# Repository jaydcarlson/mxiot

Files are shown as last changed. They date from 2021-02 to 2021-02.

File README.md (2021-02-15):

# mxiot
mxiot is a low-cost hardware prototyping platform to help you explore switching small IoT projects from bare-metal to a secure-boot-capable WiFi/BT-connected Embedded Linux system capable of running rudimentary C/C++, as well as applications written in almost any modern language or application framework (like Qt, Rust, Ruby, Python, Node.js, or .NET Core).

The heart of mxiot is the i.MX6ULZ, a 900 MHz Cortex-A7 microprocessor available [direct from NXP for $2.68](https://www.nxp.com/part/MCIMX6Z0DVM09AB#/) (even in single quantities). These are drop-in compatible with the i.MX6UL and i.MX6ULL.

mxiot pinout

### Features
The i.MX6ULZ is stripped down to the basics, but there's plenty there for most always-on IoT projects. The board exposes:
 - 3 UARTs (one with hardware flow-control signals, and one dedicated to the console)
 - Two I2C peripherals (one shared with one of the UARTs)
 - SPI with 2 chip-select signals
 - I2S with separate BCLK/WS signals for TX and RX paths.
 - 4x PWM outputs
 - Two USB ports

In addition to the DRAM and SD Card socket necessary for booting, mxiot also sports a small complement of on-board peripherals:
 - WiFi and Bluetooth connectivity
 - 4x 12-bit analog inputs, care of the Texas Instruments TLA2024
 - APA102 addressable RGB LED
 - QSPI Flash (that you can optionally boot from)
 - Pushbutton

WiFi and BLE are handled by whatever 44-pin standard SDIO-interfaced WiFi/BT *module du jour* you'd like to populate; the board supports all physically-compatible Ampak modules, as well as extremely low-cost alternatives, like the RTL8723BS modules regularly found for [around $2 from AliExpress](https://www.aliexpress.com/wholesale?catId=0&initiative_id=SB_20210214115323&SearchText=rtl8723bs), Taobao, or other distributors in Asia.

The design is open-source, and more importantly, the BOM has wide availability and doesn't lean on ICs with limited documentation or support. This means you can prototype your project around the mxiot and then copy the guts into your own design to optimize for size, power consumption, cost, or expanded functionality.

### What if I don't have Altium?
You can [download a ZIP of the repo](https://github.com/jaydcarlson/mxiot/archive/master.zip) and upload this file directly to [Altium's online viewer](https://www.altium.com/viewer/) to interact with the PCB, schematic, BOM, and 3D model of the design without having to download any software. The repo also contains a schematic and gerbers for offline viewing.

### Supports 4-layer and 6-layer stack-ups
For the sake of compactness, mxiot tightly arranges parts onto a dense 6-layer PCB measuring only 2.3 x 0.8 inches (58 x 20mm). Having said that, I've done many lower-cost 4-layer designs with mostly single-sided placements around the same guts of this board without any routing issues.

### Security
I'm a hardware guy, not a cybersecurity consultant, so I know that it's really easy to roll your eyes when people start talking about secure-boot and key storage. But seriously, folks, if you are making devices that you're going to sell to people that will connect to the internet, you have an ethical obligation to think through the security implications. You should be prototyping around hardware that has the underlying capabilities that allow you to turn on security measures during the design cycle.

The i.MX6's OTP key storage, TrustZone, and secure-boot capabilities let you establish a chain of trust from the boot ROM, to U-Boot, to the kernel, and an encrypted rootfs, which will allow you to store private data (like keys!) without having to worry as much about physical device security. You can also transport firmware updates over unencrypted channels and not have to worry about your image being reverse-engineered or modified.

### What about...?
 - *...the Raspberry Pi Zero?* While it has plenty of DRAM, the older ARM11 processor is incompatible with newer application frameworks. There's also no pathway to using the processor in a custom design, and no secure boot capability.
 - *...the Allwinner V3s or F1C100s SIPs?* These are fine for C/C++ applications or very simple Python scripts, but the V3s lacks sufficient RAM to run large, modern application frameworks, and the F1C200s is an older ARM9 cores that have dwindling software support and no security features.
 - *...the Microchip SAMA5D27 or SAM9X60 SIPs?* These both cost twice as much as the combined cost of the i.MX6ULZ and 512MB DDR3, while offering inferior performance as well as the software compatibility issues mentioned above.
 - *...the OSD32MP15x or OSD335x modules?* Unless you're literally assembling no more than a handful of units for the entirety of the project's lifecycle, these are way too expensive to justify the time savings when compared to an iMX6UL/ULL/ULZ design.

### What if I need an LCD, CSI, Ethernet, CAN, or industrial temp grades?
Grab the mxiot schematics as a starting point, but solder down a full-featured i.MX6ULL. These come in tons of different SKUs that mix and match peripherals, operating frequencies, and temperature grades. All of these are 100% electrically and mechanically compatible (in fact, mxiot started out as a 528 MHz i.MX6UL dev board from 5 years ago!).

# Hardware
## PCB Manufacture
OSHPark's test 6-layer service and JLC's 6-layer service have both been tested with the gerber files and the resulting boards pass stress-tests. While JLC's stack-up isn't ideal for the impedance targets of the design, it is much less expensive than a full-custom stack-up from a different board house. The boards will cost roughly $100 when ordered with ENIG (highly recommended). I also recommend ordering an electropolished solder stencil. I plan to do some EMC chamber testing at some point to see if the impedance mismatches on the JLC boards cause more-pronounced emissions.

## Assembly
mxiot is designed to be hand-assembled with a kitchen hotplate and low-cost hot-air gun. To assemble, paste up the top side of the PCB, place the components, and heat with a hot plate until the solder becomes molten. You can ever-so-slightly tap the BGAs on the board and they should bounce back (due to the surface tension in the solder). Pay special attention to DRAM alignment; there are a multitude of silkscreen lines that cover some, but not all, standard DDR3 footprints. 

Now is a good time to test for short-circuits and open-disconnects. If you screw up a BGA placement, you can use hot air to remove the chip, then clean the pads, apply flux, and put a bare BGA (without additional paste) on the board and re-heat it on the hotplate until it passes the "poke test."  

Next, flip the board over, paste up the bottom side, and place the remaining parts.

## Theory of Design
For being a WiFi/BT-enabled embedded Linux system, mxiot has an extremely terse BOM: fewer than 25 unique parts for an RTL8723-based configuration (and even fewer if you start removing extraneous peripherals). The mxiot design is much simpler than the reference EVK design, so I wanted to share some of the design decisions and trade-offs that went into this.

The i.MX6UL/ULL/ULZ has several internal regulators that — while not strictly staying within recommended operating conditions — allows the entire system to be powered by a 3.3V and ~1.35V rail (provided you're using DDR3L instead of 1.5V DDR3). Rather than a bulky, complex PMIC, mxiot uses two fixed-output MIC23150s to provide these rails. The 1.35V rail is somewhat-haphazardly sequenced to come on after the 3.3V rail. 

This power supply topology is designed for always-on, wall-powered applications. The platform is incapable of doing any dynamic voltage-scaling, so power consumption could be significantly worse (depending on workload) than with a PMIC or adjustable regulator.

The i.MX6 has support for a multitude of a boot modes usually prototyped by GPIO strapping. Instead of exposing these signals (which would require tons of resistor switches), I rely on the SD/MMC Manufacture Mode, where the chip will always boot from MMC0 unless the OTP boot configuration memory is flashed. If you wish to boot from QSPI flash, you'll have to initially boot from MMC, and then program the OTP memory (hoping to get it right to avoid bricking your imx6).

Rather than use a discrete WiFi/BT solution, mxiot uses standard 44-pin SDIO/UART modules that help make small-volume hand-assembly faster (as these circuits tend to have many different passive values). 

And where possible, internal pull-ups have been used (even on the POR reset pin). There are still a few places to optimize the BOM, but this will take further testing to validate. 

## Testing Status
 - [x] i.MX6ULZ
 - [x] DRAM stress tests
 - [x] RTL8723BS WiFi
 - [x] TLA2024 ADC
 - [x] USB port
 - [x] JTAG port
 
Not tested yet:
 - [ ] RTL8723BS BT
 - [ ] APA102 RGB LED
 - [ ] Pushbutton
 - [ ] QSPI Flash 

# Booting Linux
While you could use mxiot as a (very bad) single-board computer, it's designed for embedded tasks. Most of the sensors and peripherals you'll use with this board will require kernel and DTS modifications; I recommend setting up a project-specific Buildroot tree you can work out of to build a U-Boot, Linux kernel, and rootfs with the specific packages you need.

I don't have published patches yet, but you can largely use an unmodified i.MX6ULZ EVK port to get mxiot to boot. 

## Buildroot
Buildroot doesn't have an i.MX6ULZ defconfig, but you can start with an i.MX6ULL one and go from there
```
mkdir mxiot && cd mxiot
git clone https://git.busybox.net/buildroot/
cd buildroot
make imx6ullevk_defconfig
make menuconfig
```
Change **Kernel > In-tree Device Tree Source file names** to imx6ulz-14x14-evk

Go to **Bootloaders**. Change **Build system** to **Kconfig** and **Board defconfig** to **mx6ulz_14x14_evk**

## U-Boot
The big change you have to make is to switch SDHC2 to SDHC1 everywhere, since mxiot boots from the first MMC device (which is required to use SD/MMC Manufacture Mode), while the i.MX6UL, ULL, and ULZ EVKs all boot from SDHC2.

If you're in Buildroot, you can access the U-Boot menuconfig with `make uboot-menuconfig`. Make sure to enable the FSL USDHC MMC driver (`CONFIG_FSL_USDHC=y`) — I've noticed some defconfigs don't activate this driver by default. Also, change **Environment > mmc device number** (`CONFIG_SYS_MMC_ENV_DEV`) to 0.

You'll have to hack at `u-boot/include/configs/mx6ullevk.h` to switch the default SDHC2 boot device to SDHC1. These two changes should do the trick:
```
//#define CONFIG_SYS_FSL_ESDHC_ADDR   USDHC2_BASE_ADDR
#define CONFIG_SYS_FSL_ESDHC_ADDR     USDHC1_BASE_ADDR

...

//#define CONFIG_MMCROOT              "/dev/mmcblk1p2"
#define CONFIG_MMCROOT                "/dev/mmcblk0p2"
```
## Linux
There are lots of changes to make here depending on what you want your board to do. If you just want to get to a login and poke around with userspace tools, the default kernel and device tree should work.

Otherwise, here are some notes to get the onboard hardware working:

### RTL8723BS WiFi / Bluetooth module
To get WiFi working, assuming you've soldered down an RTL8723BS module, choose `CONFIG_RTL8723BS=m`

Bluetooth requires activating three-wire HCI support in the Linux kernel (`BT_HCIUART_3WIRE`) and using the appropriate [firmware and hciattach software available from lwfinger](https://github.com/lwfinger/rtl8723bs_bt).

### Analog Inputs
The 4 analog inputs are provided by an external I2C ADC, the TLA2024, which is on I2C2 at address 0x48. To bring this sensor up, edit your DTS (by default, `linux/arch/arm/boot/dts/imx6ulz-14x14-evk.dts`) to include it:
```
&i2c2 {
    ...
	tla2024: adc0@48 {
		compatible = "ti,tla2024";
		reg = <0x48>;

		v0@0 {
			single-channel = <0>;
		};

		v1@1 {
			single-channel = <1>;
		};

		v2@2 {
			single-channel = <2>;
		};

		v3@3 {
			single-channel = <3>;
		};
	};
};
```
And apply [this patch](https://patchwork.kernel.org/project/linux-iio/patch/1553608583-29006-1-git-send-email-ibtsam.haq.0x01@gmail.com/) and activate the new driver.

Other than the two I2C buses, if you want to use any of the I/O pins for their peripheral functions, or get audio working, you'll have to enable the appropriate peripherals in your DTS file and/or enable specific drivers in the Linux kernel.

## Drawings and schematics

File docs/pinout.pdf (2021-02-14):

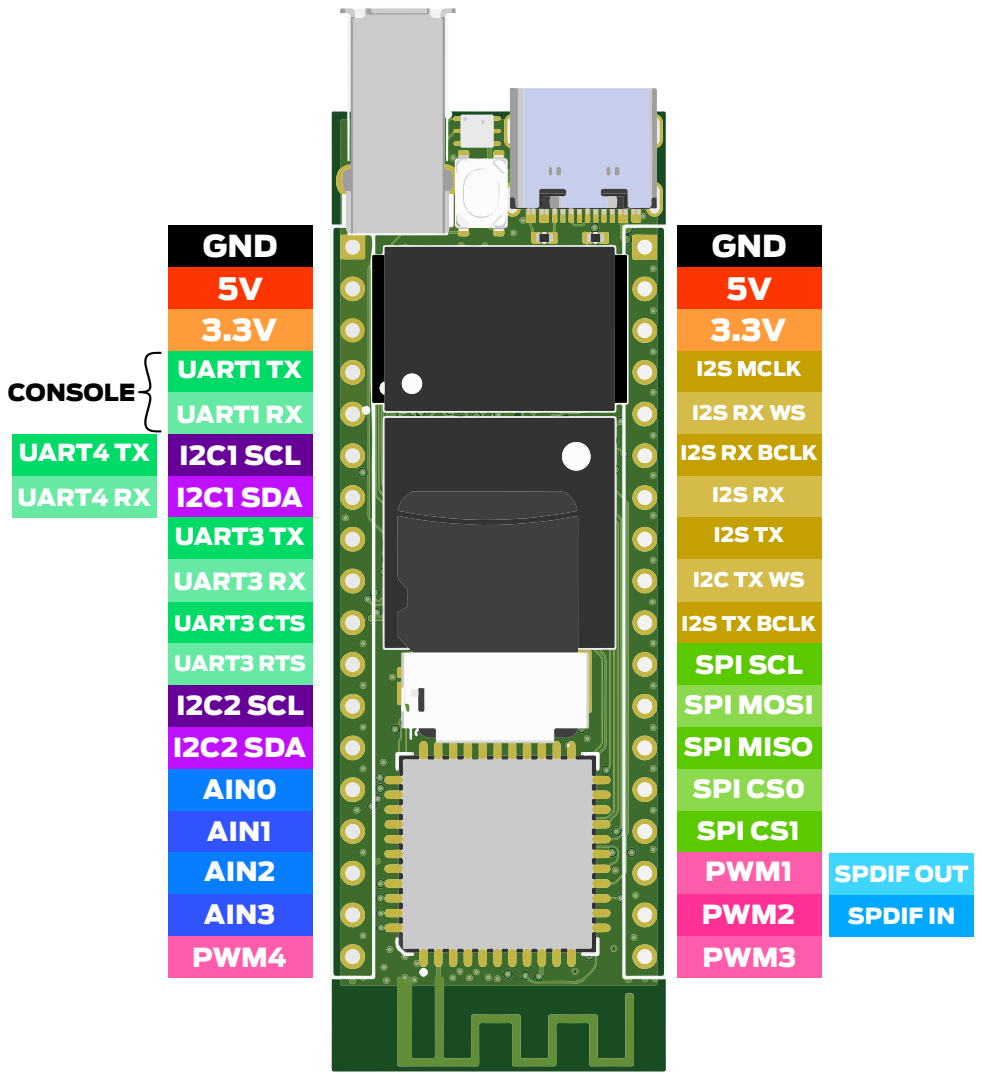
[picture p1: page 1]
GND 5V 3.3V; UART1 TX; UART1 RX; UART4 TX; UART4 RX; SPDIF OUT; SPDIF IN; UART3 TX; UART3 RX; UART3 CTS; UART3 RTS; I2C1 SCL I2C1 SDA; I2C2 SCL I2C2 SDA AIN0 AIN1 AIN2 AIN3 PWM4; I2S MCLK; I2S TX BCLK SPI SCL; I2S RX BCLK; SPI MOSI SPI MISO SPI CS0 SPI CS1 PWM1 PWM2; CONSOLE{; PWM3

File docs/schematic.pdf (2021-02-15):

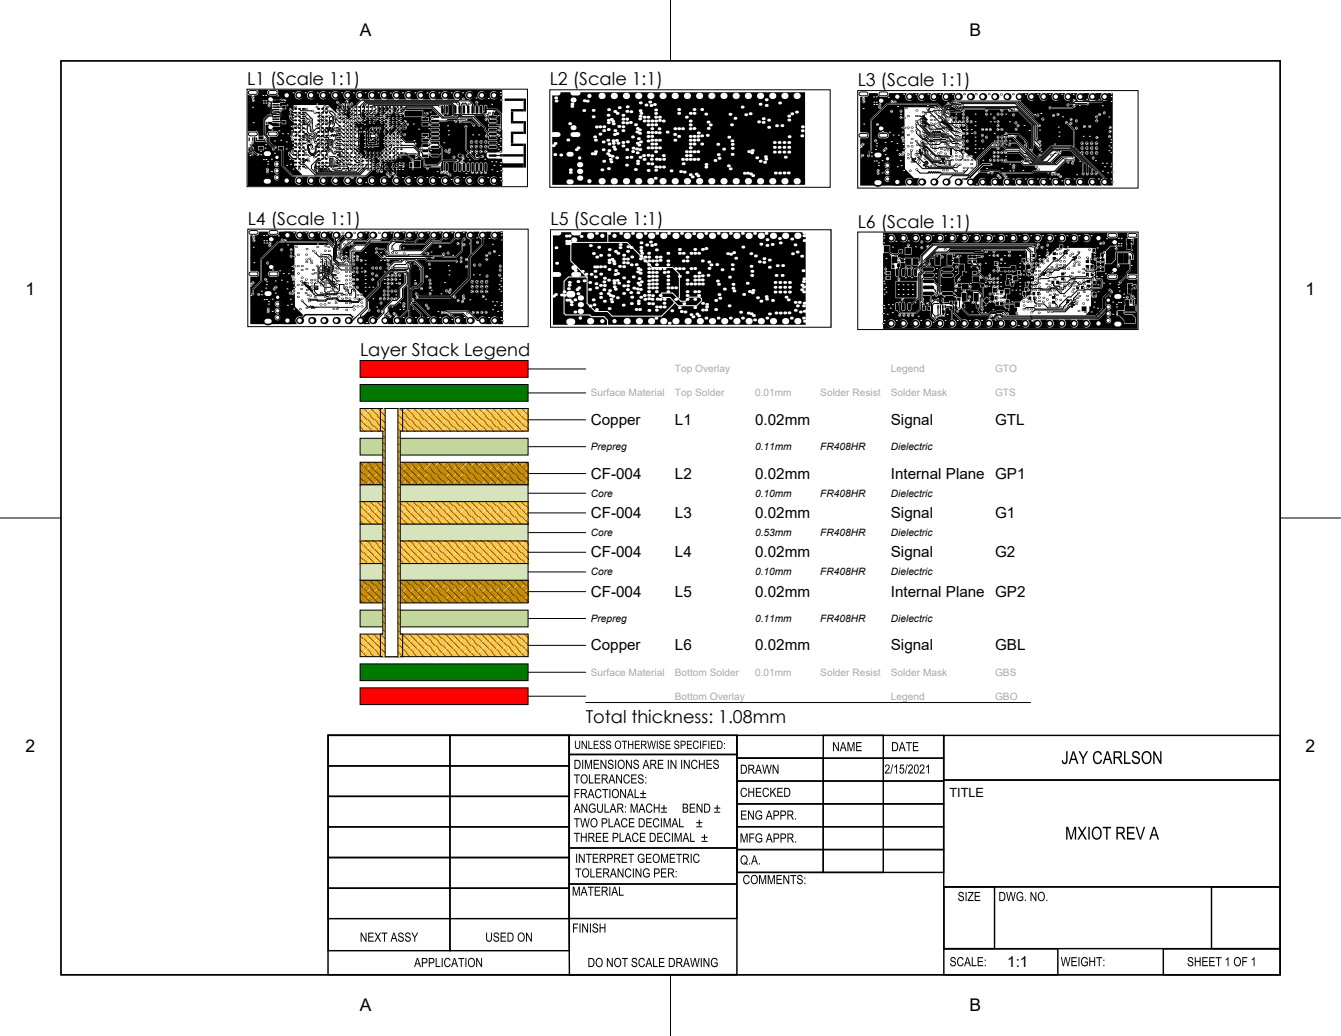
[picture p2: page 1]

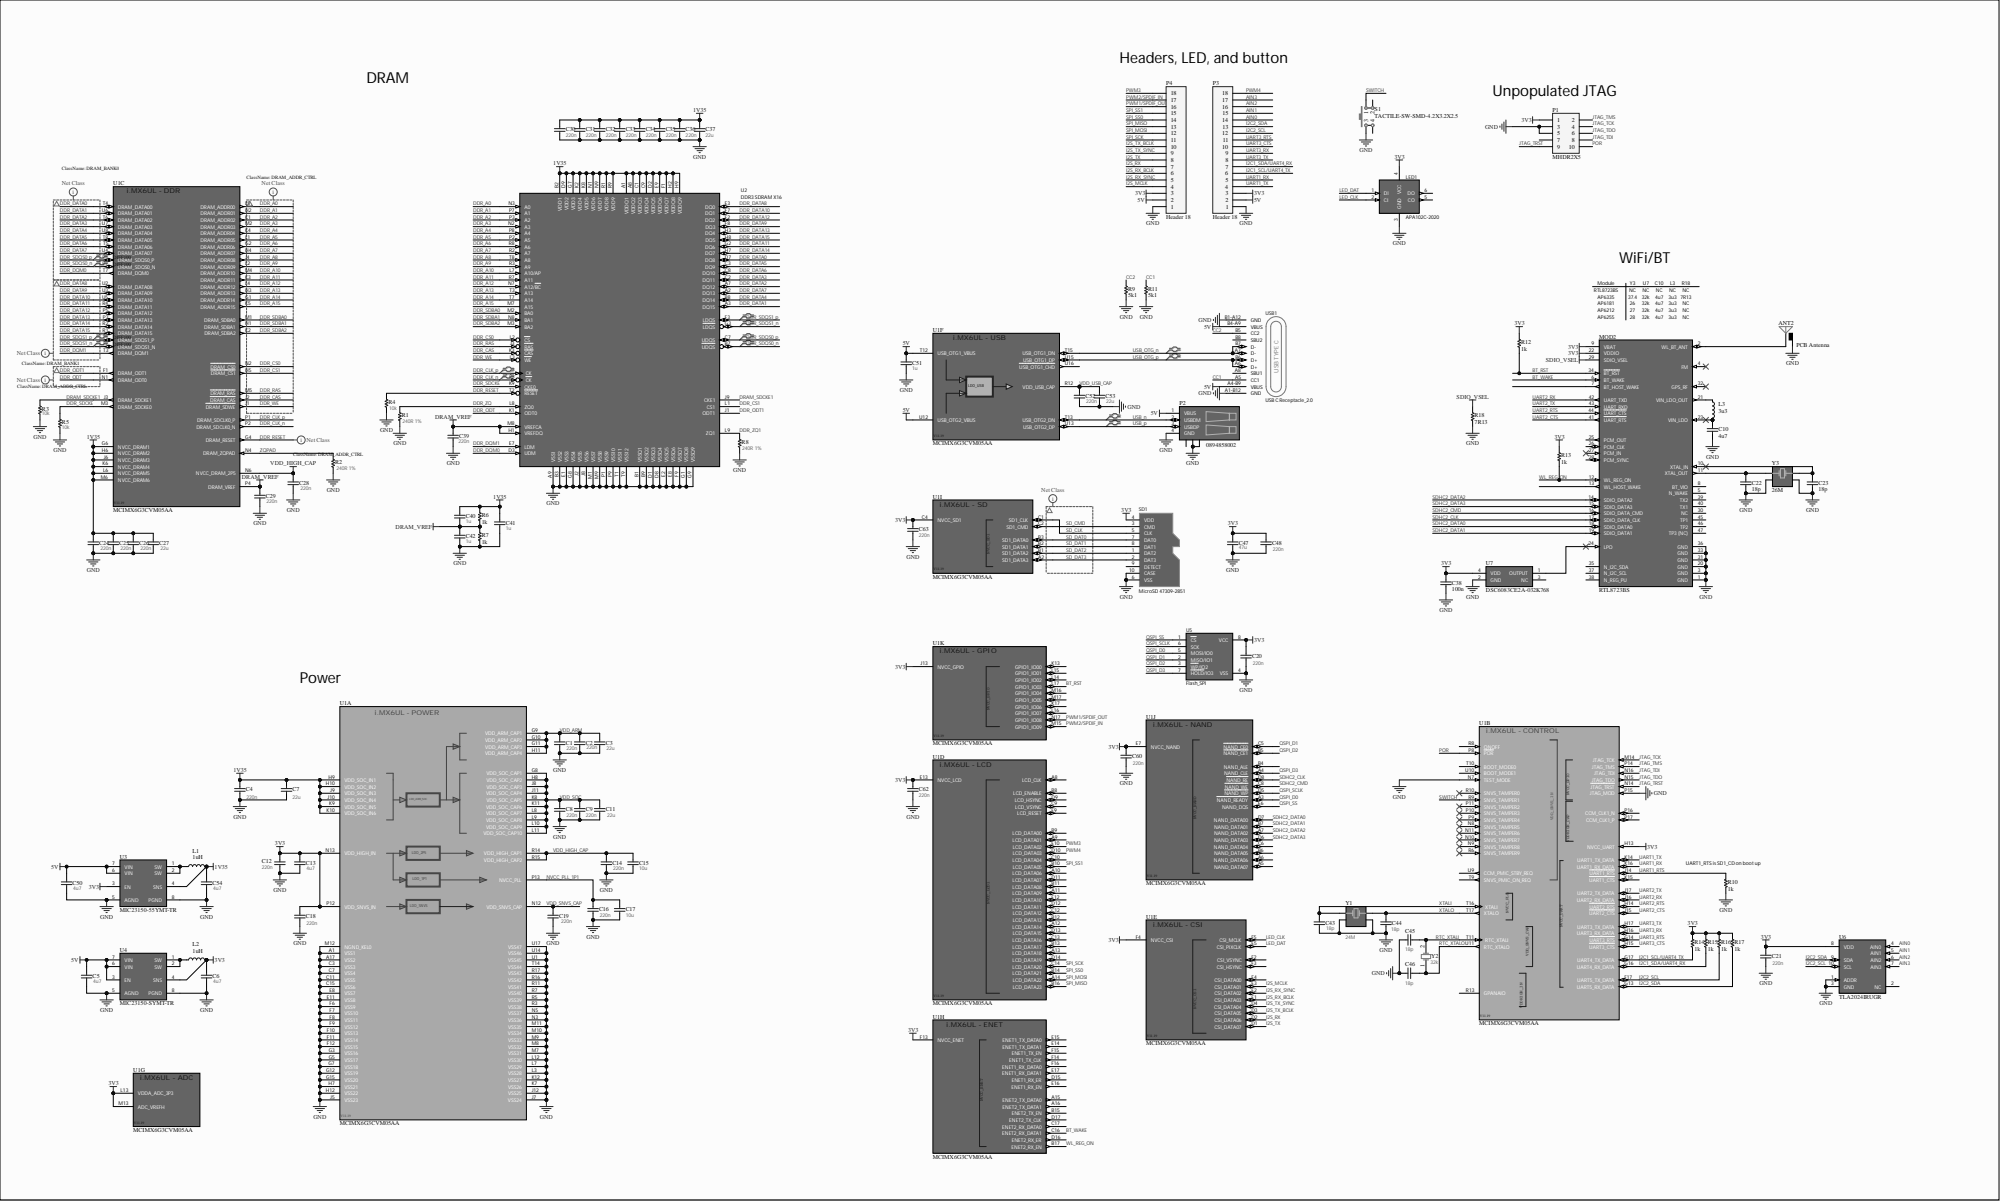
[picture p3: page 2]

Line # | Designator | Name | Quantity | Manufacturer 1 | Manufacturer Part Number 1 | Supplier 1 | Supplier Part Number 1
| C1, C2, C4, C8, C9, C12, C14, C16, C18, C19, C20, C21, C24, C25, C26, C28, C29, C30, C31, C32, C33, C34, C35, C36, C39, C48, C52, C60, C62, C63 | 220n CAPC1005N | 30 | | | [NoParam], Digi-Key | [NoParam], 490-5921-1-ND, 490-5418-1-ND
| C3, C7, C11, C27, C37, C53 | 22u CAPC1608N | 6
| C5, C6, C13, C50, C54 | 4u7CAPC1608N | 5
| C15, C17 | 10u CAPC1608N | 2
| C40, C41, C42, C51 | 1u CAPC1005N | 4 Murata | | GRM1555C1H100JA01D | Digi-Key | 490-5921-1-ND
| C43, C44, C45, C46 | 18p CAPC1005N | 4 Murata | | GRM1555C1H100JA01D | Digi-Key | 490-5921-1-ND
| C47 | 47u CAPC2012L | 1 Murata | | GRM21BR60G476ME15L | Digi-Key | 490-6469-1-ND
| L1, L2 | 1uH INDC2520X12N | 2 Samsung | | CIGW252010GL1R0MNE | Digi-Key | 1276-6932-1-ND
| LED1 | APA102C-2020 | 1
| MOD2 | RTL8723BS | 1
| P2 | 0894858002 | 1 Molex | | 0894858002 | Digi-Key | WM8627-ND
| P3, P4 | Header 18 | 2
| R1, R2, R8 | 240R 1% RESC1005N | 3 Yageo | | RC0402FR-07240RL | Digi-Key | 311-240LRCT-ND
| R3, R4, R5 | 10k RESC1005N | 3
| R6, R7, R10, R12, R13, R14, R15, R16, R17 | 1k RESC1005N | 9
| R9, R11 | 5k1 RESC1005N | 2
| S1 | TACTILE-SW-SMD-4.2X3.2X2.5 | 1
| SD1 | MicroSD 47309-2851 | 1 Molex | | 47309-2851 | Digi-Key | WM6701TR-ND
| U1 | MCIMX6G3CVM05AA | 1 NXP | Semiconductors | MCIMX6Z0DVM09AB
| U2 | DDR3 SDRAM X16 | 1 Micron | Technology | MT41K256M16TW-107 IT:P | LCSC | C524869
| U3 | MIC23150-55YMT-TR | 1 Microchip | | MIC23150-55YMT-TR | Digi-Key | 576-3651-1-ND
| U4 | MIC23150-SYMT-TR | 1 Microchip | | MIC23150-SYMT-TR | Digi-Key | 576-3314-1-ND
| U5 | Flash_SPI | 1
| U6 | TLA2024IRUGR | 1 Texas Instruments TLA2024IRUGR | | | Digi-Key | 296-51661-1-ND
| USB1 | USB C Receptacle_2.0 | 1
| Y1 | 24M XTAL3225-4-N | 1 Murata | | XRCGB24M000F3M00R0 | Digi-Key | 490-5576-1-ND
| Y2 | 32k ABS07 | 1 Seiko | | SC32S-7PF20PPM | Digi-Key | 728-1074-1-ND
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

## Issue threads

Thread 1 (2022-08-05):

Recommended operating conditions

fglasmachers, 2022-08-05:
Thank you for sharing the design.

I am trying to understand the following sentence in your Readme:

> The i.MX6UL/ULL/ULZ has several internal regulators that — while not strictly staying within recommended operating conditions — allows the entire system to be powered by a 3.3V and ~1.35V rail (provided you're using DDR3L instead of 1.5V DDR3).

What are the recommended operating conditions the design does not strictly stay in? Should I use a dedicated 1.35V rail for the DDR3L ram instead of sharing it with VDD_SOC_IN?

jaydcarlson, 2022-08-05:
You should [consult the datasheet](https://www.nxp.com/docs/en/data-sheet/IMX6ULLCEC.pdf#page=24) for the part you're designing around, which will have detailed operating specifications. At 900 MHz, the i.MX6ULL has a recommended VDD_SOC_IN range of 1.375V to 1.5V. So yes, you could have a 1.35V rail for the DDR3L and a separate 1.4V rail (or whatever) for VDD_SOC_IN. For low-power applications, you'd actually want this rail to dynamically scale based on operating frequency, so you'd probably just use a supported PMIC, which will have the whole complement of regulators necessary.

However, for a wall-powered always-on design, that all seems a bit ridiculous, so I've always just used a single regulator for both DDR3L and VDD_SOC_IN rails and have never had issues on any of the boards I've designed with this strategy.

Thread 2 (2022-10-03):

Card did not respond to voltage select!

chupalt, 2022-10-03:
I've built one of your boards and am fairly certain there are no issues with the build.  I've been able to connect over usb using uuu and have been able to run the DDR test and calibration with no issues.

I'm trying to follow your instructions to get the mxiot booting off of an SD card.  I've made the changes you referenced in your readme in menuconfig and uboot-menuconfig, but uboot keeps giving me the following error related to voltage selection of the SD card. Did you run into a similar issue?  If not, do you know what version of buildroot/u-boot you used?

U-Boot 2021.10 (Oct 03 2022 - 12:15:05 -0700)

CPU:   Freescale i.MX6ULZ rev1.1 900 MHz (running at 396 MHz)
CPU:   Commercial temperature grade (0C to 95C) at 49C
Reset cause: WDOG
Model: Freescale i.MX6 ULZ 14x14 EVK Board
Board: MX6ULZ 14x14 EVK
DRAM:  512 MiB
MMC:   FSL_SDHC: 0, FSL_SDHC: 1
Loading Environment from MMC... Card did not respond to voltage select! : -110
*** Warning - No block device, using default environment

In:    serial
Out:   serial
Err:   serial
Hit any key to stop autoboot:  0
Card did not respond to voltage select! : -110
Card did not respond to voltage select! : -110
Card did not respond to voltage select! : -110

Thanks for publishing the design, and for the various blog posts on embedded linux development.

chupalt, 2022-10-05:
Closing the issue, as I was able to get it booting.  Had to be an issue with that particular board's SD card interface.  I built a second one and was able to get it going.  One issue I ran into was that you have to use some older SD cards because of the 3.3V fixed supply for the SD card.  Found a post that said I can change the device tree as follows so that I'm not limited on the SD cards that can be used.  Trying it now.

&usdhc1 {
pinctrl-names = "default";
pinctrl-0 = <&pinctrl_usdhc1>;
status = "okay";
};

Closed 2022-10-05.

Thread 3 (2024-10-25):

Crystal and CL selection

ghazanhaider, 2024-10-25:
I have a design very similar to yours that refuses to start up.

XRCGB24M000FBP12R0 vs your XRCGB24M000F3M00R0

They both specify 6pF CL but the ESR is different.

I noticed that you have 18pF load capacitors in the schematic for this crystal. If I assume 2pF stray, I get (6 - 2)x2 = 8pF which seems to be very far from 18pF

Did you use 18pF CL with XRCGB24M000FBP12R0 or did you have to modify anything?

My setup:
- MCIMX6Z0DVM09AB (same as yours)
- XRCGB24M000F3M00R0 (6pF 80ohm ESR)
- Tried load capacitors of 10nF and 22nF (5% 0402, 50V)
- Dual RT8070 DC/DC supplies with the 3.3V feeding the EN pin of the 1.35V similar to your setup.
- POR_B has 10k pullup and 0.1nF shunt to ground to delay it
- Tried all 4 combinations of boot mode.
- 3 boards with the third having all other objects not placed to simplify the circuit.
- Measuring the crystal pins with 10x scope shos XTALI at 3.3V flat and XTALO 0V.
- Similar setup with my Microchip designs have alwaysworked

Closed 2024-10-25.

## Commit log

2021-02-14 Initial add
    [mxiot.PrjPcb, mxiot.SchDoc]
2021-02-15 Documentaion improvements
    [mxiot.PrjPcb, mxiot.SchDoc]
2021-02-15 Add gerbers and schematic docs
    [mxiot.GBL, mxiot.GBO, mxiot.GBP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]
2021-02-15 Added "design theory" section and recommended manfacture / assembly instructions
2021-02-15 Updated BOM, swapped L for N footprint on ZQ resistor to make placement easier.
    [mxiot.GBL, mxiot.GBO, mxiot.GBP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]
